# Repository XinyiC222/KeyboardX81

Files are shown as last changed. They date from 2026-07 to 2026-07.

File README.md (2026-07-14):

# Keyboard81X

A custom 75% PCB keyboard with a rotary encoder and 81 keys.

## Build Notes

- PCB was designed in **KiCad** using a keyswitch plugin.
  - If you are trying to find it here are the ones I used:
    - **KLE Placer**  /Organize the keys and diodes automatically based on .json file
    - **JLCPCB tools** / used for BOM and Placement for JLC pcbs
- Case was modeled in **Fusion**.
## Tools I used
- Plate was generated with: <http://builder.swillkb.com/>
- Keyboard Layout Editor: <https://www.keyboard-layout-editor.com/>
- Keycaps used in the model: <https://github.com/anhthang/dsa-keycap>
- Footprint Library I used in Kicad: <https://github.com/daprice/keyswitches.pretty>

## How To Build Your Own! <h3>PCB</h3>

1. Build your layout with the layout editor I mentioned in the tools I used.
2. Download the .json file from there.
3. In KiCad schematics choose your microcontroller or just use a chip. For mine, I used a RP2040 chip and built somewhat of a dev board inside the project. That includes the Flash Memory to store the code, Crystal Oscillator (it's like the conductor), USB for power with a voltage regulator, and some capacitors.
4. Then add the current amount of MX_SW_HS you need based on the layout you made.
5. Add the same amount of diodes so each key has one.
6. Then after that you can add some MX_Stab for the ones you want to stabilize. Some keys like the spacebar need stabilizers, so you can change them to different footprints from the other keys.
7. Add footprint to all your components and don't forget to **Annotate the entire Schematics**
8. Now when designing the PCB, using the .json file and the KLE Placer plugin, you can easily place them all accordingly.
9. Remember to add a border around to create the edge of the PCB in the Edge.cut layer.
10. Organize all the components to your liking and route all of them to each other.
11. **Generate the Gerber Files!**
12. Then if you were to use JLCPCB, you can use the JLCPCB tools to find all the components and create the correct BOM and CPL.
13. You can then upload those files into JLCPCB!!

<h3>Case</h3>

1. Go into Fusion and create a new project.
2. Download the 3D view of your keyboard from KiCad and upload it (for reference!)
3. Then make the case around it any way you like. If you are 3D printing remember that prints can shrink so you need to **account for tolerances especially holes**
4. you can add a plate and any type of mounting you want
5. If you are adding a plate, the plate generater I included above might be helpful
6. For the plate if you are 3D printing with PLA, having it at 1.5mm thick is usually not strong enough. Set it to **3mm** but leave the area around the stabilizers to be 1.5mm

<h3>That's pretty much a good summary of how to build your own keyboard! Thanks for reading it and I hope you learned something new. This is my first big project and definitely my first keyboard build so I don't expect everything to be correct. So if you are building this based off of mine, it's not guaranteed to work!!</h3>

## BOM
Everything under quality is the amount they give for the price I payed for. Some come with more than I needed.

| Item | Purpose | Price | Quantity | Source |
|---|---|---|---|---|
| Screw-in Stabilizers | stab for space bar etc | $1.78 | has 1 6.25u and two 2u | [Aliexpress](https://www.aliexpress.com/item/3256807050530252.html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) |
| Tactile switch | switches | $8.56 | x100 | [Aliexpress](https://www.aliexpress.com/item/3256812192263951.html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) |
| 1N4148 SOD-123 | diodes for each switch | $1.67 | x100 | [Aliexpress](https://www.aliexpress.com/item/3256801606142520.html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) |
| Hot Swap Sockets | hot swap keys | $8.29 | x110 | [Aliexpress](https://www.aliexpress.com/item/3256809001206372.html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) |
| SMD | Reset button | $1.63 | x50 | [Aliexpress](https://www.aliexpress.com/item/3256805092773328.html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) |
| Type C Female | PCB for power | $2.24 | x3 | [Aliexpress](https://www.aliexpress.com/item/3256804989275660.html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) |
| Keycaps | for the Keys | $4.67 | x104 | [Aliexpress](https://www.aliexpress.com/item/3256808108935624.html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) |

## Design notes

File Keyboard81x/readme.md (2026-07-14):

# keyboard81x

keyboard81x

*A short description of the keyboard/project*

* Keyboard Maintainer: [Amelia Chen](https://github.com/Xinyic222)
* Hardware Supported: *The PCBs, controllers supported*
* Hardware Availability: *Links to where you can find this hardware*

Make example for this keyboard (after setting up your build environment):

    make keyboard81x:default

Flashing example for this keyboard:

    make keyboard81x:default:flash

See the [build environment setup](https://docs.qmk.fm/#/getting_started_build_tools) and the [make instructions](https://docs.qmk.fm/#/getting_started_make_guide) for more information. Brand new to QMK? Start with our [Complete Newbs Guide](https://docs.qmk.fm/#/newbs).

## Bootloader

Enter the bootloader in 3 ways:

* **Bootmagic reset**: Hold down the key at (0,0) in the matrix (usually the top left key or Escape) and plug in the keyboard
* **Physical reset button**: Briefly press the button on the back of the PCB - some may have pads you must short instead
* **Keycode in layout**: Press the key mapped to `QK_BOOT` if it is available

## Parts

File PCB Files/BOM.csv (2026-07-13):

Comment | Designator | Footprint | LCSC | Quantity
0.1uF | C11,C12,C15,C2,C3,C4,C5,C6,C7,C8,C9 | C_0402_1005Metric | C1525 | 11
10k | R5 | C_0402_1005Metric | C25744 | 1
10uF | C13,C14 | C_0201_0603Metric | C19702 | 2
1k | R6,R7 | C_0402_1005Metric | C11702 | 2
1uF | C1,C10 | C_0402_1005Metric | C52923 | 2
27 | R3,R4 | C_0402_1005Metric | C25100 | 2
33pF | C16,C17 | C_0402_1005Metric | C1562 | 2
5.1k | R1,R2 | R_0402_1005Metric | C25905 | 2
Crystal_GND24 | Y2 | Crystal_SMD_3225-4Pin_3.2x2.5mm | C9002 | 1
MCP1700x-330xxTT | U3 | SOT-23 | C39051 | 1
MX_SW_HS | SW45 | SW_MX_HS_CPG151101S11_1.75u | C49352235 | 1
RP2040 | U2 | QFN-56-1EP_7x7mm_P0.4mm_EP3.2x3.2mm | C2040 | 1
W25Q16JVZPIQ TR | U4 | Winbond_USON-8-1EP_3x2mm_P0.5mm_EP0.2x1.6mm | C2843335 | 1
MX_SW_HS | SW78 | SW_MX_HS_CPG151101S11_1.25u |  | 1
MX_SW_HS | SW77 | SW_MX_HS_CPG151101S11_1.5u |  | 1
MX_SW_HS | SW59 | SW_Hotswap_Kailh_MX_2.25u |  | 1
MX_SW_HS | SW57 | SW_Hotswap_Kailh_MX_2.00u |  | 1
MX_SW_HS | SW28 | SW_Hotswap_Kailh_MX_2.00u |  | 1
MX_SW_HS | SW75 | SW_MX_HS_CPG151101S11_1.5u |  | 1
MX_SW_HS | SW76 | SW_Hotswap_Kailh_MX_6.25u |  | 1
MX_stab | S57 | STAB_MX_P_2.25u |  | 1
MX_stab | S28 | STAB_MX_P_2u |  | 1
MX_stab | S76 | STAB_MX_P_6.25u |  | 1
MX_stab | S59 | STAB_MX_P_2.25u |  | 1
MX_stab | S70 | STAB_MX_P_2u |  | 1
D_Small | D10 | D_SOD-123 |  | 1
D_Small | D18 | D_SOD-123 |  | 1
MX_SW_HS | SW54 | SW_MX_HS_CPG151101S11_1u |  | 1
D_Small | D3 | D_SOD-123 |  | 1
D_Small | D7 | D_SOD-123 |  | 1
D_Small | D63 | D_SOD-123 |  | 1
MX_SW_HS | SW5 | SW_MX_HS_CPG151101S11_1u |  | 1
MX_SW_HS | SW79 | SW_MX_HS_CPG151101S11_1u |  | 1
MX_SW_HS | SW42 | SW_MX_HS_CPG151101S11_1u |  | 1
MX_SW_HS | SW23 | SW_MX_HS_CPG151101S11_1u |  | 1
D_Small | D57 | D_SOD-123 |  | 1
MX_SW_HS | SW48 | SW_MX_HS_CPG151101S11_1u |  | 1
MX_SW_HS | SW4 | SW_MX_HS_CPG151101S11_1u |  | 1
D_Small | D77 | D_SOD-123 |  | 1
D_Small | D5 | D_SOD-123 |  | 1
D_Small | D66 | D_SOD-123 |  | 1
D_Small | D31 | D_SOD-123 |  | 1
MX_SW_HS | SW19 | SW_MX_HS_CPG151101S11_1u |  | 1
D_Small | D38 | D_SOD-123 |  | 1
D_Small | D2 | D_SOD-123 |  | 1
D_Small | D24 | D_SOD-123 |  | 1
MX_SW_HS | SW69 | SW_MX_HS_CPG151101S11_1u |  | 1
MX_SW_HS | SW63 | SW_MX_HS_CPG151101S11_1u |  | 1
MX_SW_HS | SW15 | SW_MX_HS_CPG151101S11_1u |  | 1
D_Small | D53 | D_SOD-123 |  | 1
MX_SW_HS | SW56 | SW_MX_HS_CPG151101S11_1u |  | 1
D_Small | D79 | D_SOD-123 |  | 1
MX_SW_HS | SW51 | SW_MX_HS_CPG151101S11_1u |  | 1
D_Small | D23 | D_SOD-123 |  | 1
MX_SW_HS | SW70 | SW_MX_HS_CPG151101S11_1.75u |  | 1
MX_SW_HS | SW12 | SW_MX_HS_CPG151101S11_1u |  | 1
MX_SW_HS | SW52 | SW_MX_HS_CPG151101S11_1u |  | 1
MX_SW_HS | SW68 | SW_MX_HS_CPG151101S11_1u |  | 1
D_Small | D78 | D_SOD-123 |  | 1
MX_SW_HS | SW11 | SW_MX_HS_CPG151101S11_1u |  | 1
MX_SW_HS | SW73 | SW_MX_HS_CPG151101S11_1.25u |  | 1
MX_SW_HS | SW65 | SW_MX_HS_CPG151101S11_1u |  | 1
MX_SW_HS | SW34 | SW_MX_HS_CPG151101S11_1u |  | 1
MX_SW_HS | SW43 | SW_MX_HS_CPG151101S11_1.5u |  | 1
D_Small | D8 | D_SOD-123 |  | 1
MX_SW_HS | SW66 | SW_MX_HS_CPG151101S11_1u |  | 1
MX_SW_HS | SW33 | SW_MX_HS_CPG151101S11_1u |  | 1
D_Small | D59 | D_SOD-123 |  | 1
D_Small | D47 | D_SOD-123 |  | 1
D_Small | D12 | D_SOD-123 |  | 1
MX_SW_HS | SW55 | SW_MX_HS_CPG151101S11_1u |  | 1
D_Small | D51 | D_SOD-123 |  | 1
MX_SW_HS | SW35 | SW_MX_HS_CPG151101S11_1u |  | 1
MX_SW_HS | SW60 | SW_MX_HS_CPG151101S11_1u |  | 1
D_Small | D75 | D_SOD-123 |  | 1
D_Small | D73 | D_SOD-123 |  | 1
D_Small | D70 | D_SOD-123 |  | 1
MX_SW_HS | SW49 | SW_MX_HS_CPG151101S11_1u |  | 1
MX_SW_HS | SW38 | SW_MX_HS_CPG151101S11_1u |  | 1
MX_SW_HS | SW46 | SW_MX_HS_CPG151101S11_1u |  | 1
MX_SW_HS | SW21 | SW_MX_HS_CPG151101S11_1u |  | 1
MX_SW_HS | SW24 | SW_MX_HS_CPG151101S11_1u |  | 1
D_Small | D52 | D_SOD-123 |  | 1
MX_SW_HS | SW22 | SW_MX_HS_CPG151101S11_1u |  | 1
D_Small | D54 | D_SOD-123 |  | 1
D_Small | D56 | D_SOD-123 |  | 1
MX_SW_HS | SW53 | SW_MX_HS_CPG151101S11_1u |  | 1
D_Small | D21 | D_SOD-123 |  | 1
D_Small | D43 | D_SOD-123 |  | 1
MX_SW_HS | SW36 | SW_MX_HS_CPG151101S11_1u |  | 1
D_Small | D33 | D_SOD-123 |  | 1
D_Small | D68 | D_SOD-123 |  | 1
D_Small | D14 | D_SOD-123 |  | 1
D_Small | D46 | D_SOD-123 |  | 1
D_Small | D80 | D_SOD-123 |  | 1
D_Small | D49 | D_SOD-123 |  | 1
D_Small | D42 | D_SOD-123 |  | 1
D_Small | D69 | D_SOD-123 |  | 1
MX_SW_HS | SW47 | SW_MX_HS_CPG151101S11_1u |  | 1
D_Small | D55 | D_SOD-123 |  | 1
D_Small | D61 | D_SOD-123 |  | 1
MX_SW_HS | SW3 | SW_MX_HS_CPG151101S11_1u |  | 1
MX_SW_HS | SW32 | SW_MX_HS_CPG151101S11_1u |  | 1
D_Small | D62 | D_SOD-123 |  | 1
D_Small | D48 | D_SOD-123 |  | 1
MX_SW_HS | SW9 | SW_MX_HS_CPG151101S11_1u |  | 1
MX_SW_HS | SW1 | SW_MX_HS_CPG151101S11_1u |  | 1
MX_SW_HS | SW74 | SW_MX_HS_CPG151101S11_1.25u |  | 1
MX_SW_HS | SW20 | SW_MX_HS_CPG151101S11_1u |  | 1
MX_SW_HS | SW27 | SW_MX_HS_CPG151101S11_1u |  | 1
MX_SW_HS | SW67 | SW_MX_HS_CPG151101S11_1u |  | 1
D_Small | D37 | D_SOD-123 |  | 1
D_Small | D45 | D_SOD-123 |  | 1
MX_SW_HS | SW80 | SW_MX_HS_CPG151101S11_1u |  | 1
D_Small | D34 | D_SOD-123 |  | 1
MX_SW_HS | SW16 | SW_MX_HS_CPG151101S11_1u |  | 1
MX_SW_HS | SW26 | SW_MX_HS_CPG151101S11_1u |  | 1
D_Small | D74 | D_SOD-123 |  | 1
MX_SW_HS | SW50 | SW_MX_HS_CPG151101S11_1u |  | 1
MX_SW_HS | SW17 | SW_MX_HS_CPG151101S11_1u |  | 1
D_Small | D30 | D_SOD-123 |  | 1
D_Small | D16 | D_SOD-123 |  | 1
D_Small | D40 | D_SOD-123 |  | 1
MX_SW_HS | SW37 | SW_MX_HS_CPG151101S11_1u |  | 1
D_Small | D6 | D_SOD-123 |  | 1
D_Small | D9 | D_SOD-123 |  | 1
MX_SW_HS | SW25 | SW_MX_HS_CPG151101S11_1u |  | 1
D_Small | D13 | D_SOD-123 |  | 1
D_Small | D20 | D_SOD-123 |  | 1
MX_SW_HS | SW62 | SW_MX_HS_CPG151101S11_1u |  | 1
MX_SW_HS | SW41 | SW_MX_HS_CPG151101S11_1u |  | 1
MX_SW_HS | SW2 | SW_MX_HS_CPG151101S11_1u |  | 1
D_Small | D17 | D_SOD-123 |  | 1
MX_SW_HS | SW39 | SW_MX_HS_CPG151101S11_1u |  | 1
D_Small | D27 | D_SOD-123 |  | 1
D_Small | D71 | D_SOD-123 |  | 1
MX_SW_HS | SW30 | SW_MX_HS_CPG151101S11_1.5u |  | 1
D_Small | D15 | D_SOD-123 |  | 1
MX_SW_HS | SW64 | SW_MX_HS_CPG151101S11_1u |  | 1
D_Small | D64 | D_SOD-123 |  | 1
D_Small | D41 | D_SOD-123 |  | 1
D_Small | D4 | D_SOD-123 |  | 1
D_Small | D65 | D_SOD-123 |  | 1
D_Small | D11 | D_SOD-123 |  | 1
D_Small | D67 | D_SOD-123 |  | 1
MX_SW_HS | SW18 | SW_MX_HS_CPG151101S11_1u |  | 1
D_Small | D76 | D_SOD-123 |  | 1
D_Small | D26 | D_SOD-123 |  | 1
D_Small | D35 | D_SOD-123 |  | 1
MX_SW_HS | SW61 | SW_MX_HS_CPG151101S11_1u |  | 1
MX_SW_HS | SW10 | SW_MX_HS_CPG151101S11_1u |  | 1
D_Small | D1 | D_SOD-123 |  | 1
MX_SW_HS | SW13 | SW_MX_HS_CPG151101S11_1u |  | 1
MX_SW_HS | SW71 | SW_MX_HS_CPG151101S11_1u |  | 1
D_Small | D39 | D_SOD-123 |  | 1
D_Small | D25 | D_SOD-123 |  | 1
D_Small | D50 | D_SOD-123 |  | 1
D_Small | D22 | D_SOD-123 |  | 1
D_Small | D60 | D_SOD-123 |  | 1
MX_SW_HS | SW40 | SW_MX_HS_CPG151101S11_1u |  | 1
D_Small | D19 | D_SOD-123 |  | 1
MX_SW_HS | SW7 | SW_MX_HS_CPG151101S11_1u |  | 1
MX_SW_HS | SW6 | SW_MX_HS_CPG151101S11_1u |  | 1
MX_SW_HS | SW8 | SW_MX_HS_CPG151101S11_1u |  | 1
D_Small | D36 | D_SOD-123 |  | 1
D_Small | D28 | D_SOD-123 |  | 1
D_Small | D32 | D_SOD-123 |  | 1
MX_SW_HS | SW31 | SW_MX_HS_CPG151101S11_1u |  | 1
USB_C_Receptacle_USB2.0_14P | J2 | USB_C_Receptacle_HRO_TYPE-C-31-M-12 |  | 1
RotaryEncoder_Switch | SW14 | Encoder_EC11_MX |  | 1
MX_SW_HS | SW29 | SW_MX_HS_CPG151101S11_1u |  | 1
D_Small | D58 | D_SOD-123 |  | 1
MX_SW_HS | SW58 | SW_MX_HS_CPG151101S11_1u |  | 1
D_Small | D44 | D_SOD-123 |  | 1
D_Small | D81 | D_SOD-123 |  | 1
MX_SW_HS | SW72 | SW_MX_HS_CPG151101S11_1u |  | 1
MX_SW_HS | SW81 | SW_MX_HS_CPG151101S11_1u |  | 1
D_Small | D72 | D_SOD-123 |  | 1
D_Small | D29 | D_SOD-123 |  | 1
MX_SW_HS | SW44 | SW_MX_HS_CPG151101S11_1u |  | 1
SW_Push | SW82 | SW_Push_SPST_NO_Alps_SKRK |  | 1

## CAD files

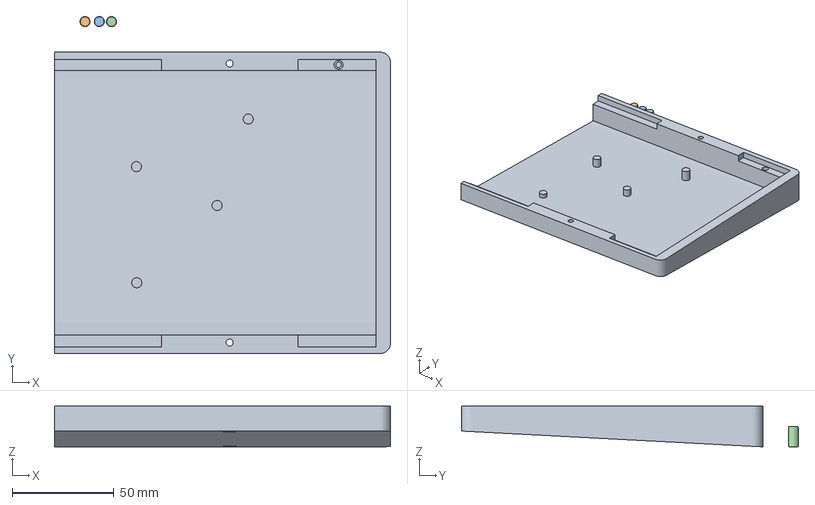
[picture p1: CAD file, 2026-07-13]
Print Files/BottomR.3mf
165.0 x 165.5 x 20.0 mm
bottom right
stub
stub2
stub3

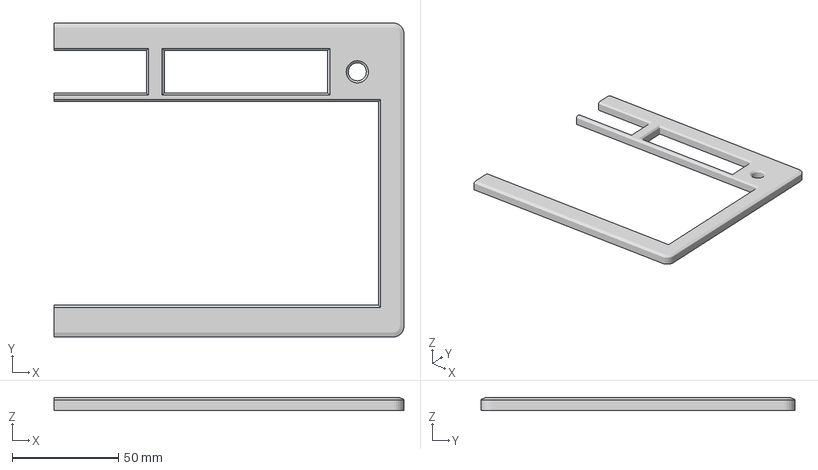
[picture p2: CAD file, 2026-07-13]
Print Files/Case/TopR.3mf
165.0 x 148.0 x 6.00 mm

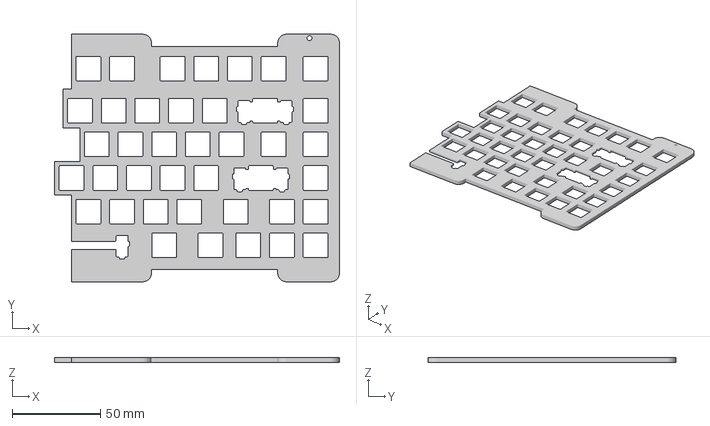
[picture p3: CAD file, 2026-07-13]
Print Files/Plate/PlateR.3mf
161.3 x 140.2 x 3.00 mm

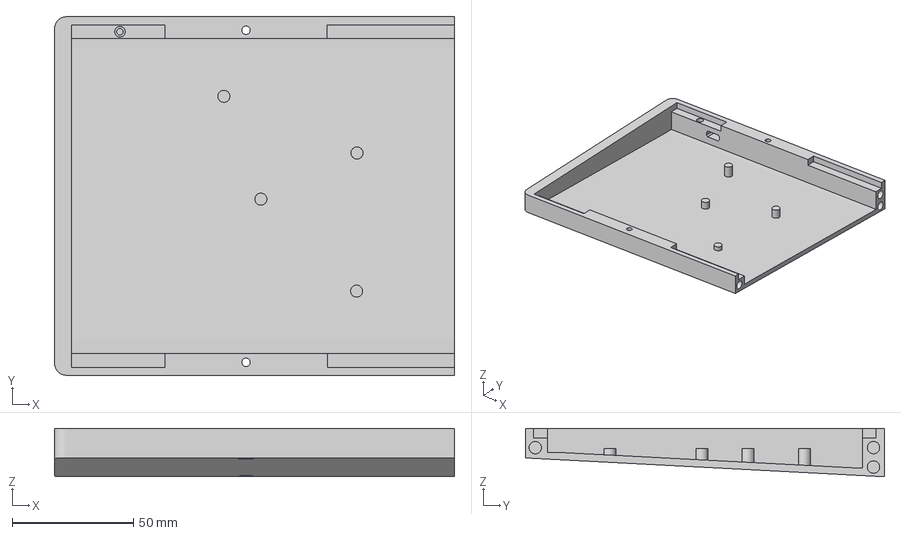
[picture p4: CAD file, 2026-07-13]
Print Files/Case/BottomL.3mf
165.0 x 148.0 x 20.0 mm

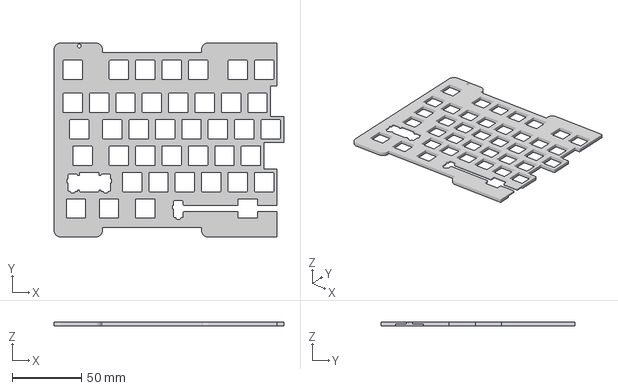
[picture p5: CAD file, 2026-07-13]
Print Files/PlateL.3mf
166.0 x 140.2 x 3.00 mm

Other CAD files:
Print Files/Case/TopL.3mf
Project Files/Fusion/Case.f3d
Project Files/Fusion/Knob.f3d
Project Files/Fusion/Plate.f3d

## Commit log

2026-05-17 Enhance README with build notes and BOM template
    Expanded the README with additional details about the keyboard's design and build notes.
2026-07-13 Revise plate instructions in README
    Updated instructions for adding a plate and included a reference to the plate generator.
2026-07-13 Rename Amelia's Keyboard.kicad_pro to Project Files/Kicad/Amelia's Keyboard.kicad_pro
2026-07-13 Rename Amelia's Keyboard.kicad_sch to Project Files/Kicad/Amelia's Keyboard.kicad_sch
    [Amelia's Keyboard.kicad_sch]
2026-07-13 Rename Print Files/BottomL.3mf to Print Files/Case/BottomL.3mf
    [BottomL.3mf]
2026-07-13 Rename Print Files/TopL.3mf to Print Files/Case/TopL.3mf
    [TopL.3mf]
2026-07-13 Rename Print Files/TopR.3mf to Print Files/Case/TopR.3mf
    [TopR.3mf]
2026-07-13 Rename Print Files/PlateR.3mf to Print Files/Plate/PlateR.3mf
    [PlateR.3mf]
